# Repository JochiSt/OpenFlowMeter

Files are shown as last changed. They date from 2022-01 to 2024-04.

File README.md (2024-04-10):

# OpenFlowMeter
## Purpose
Measuring flow of gases and maybe liquids. 

## Principle
Measures the volume flow by the amount of heat transferred to a gas flow. This can be either done by constantly heating the sensor or by evaluating temperature cycles.

# Hardware
The hardware is based around two voltage controlled current sources, which are controlled and readout via a STM32F103 microcontroller. 
The controller provides the ADCs for reading the voltages and current as well as the digital communication to the outside of the PCB.

## Photographs of the populated PCB
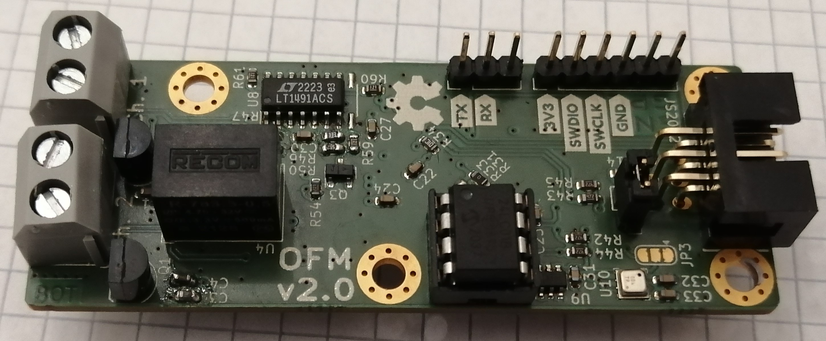
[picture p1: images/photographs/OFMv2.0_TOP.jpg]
Picture of the PCB from TOP side


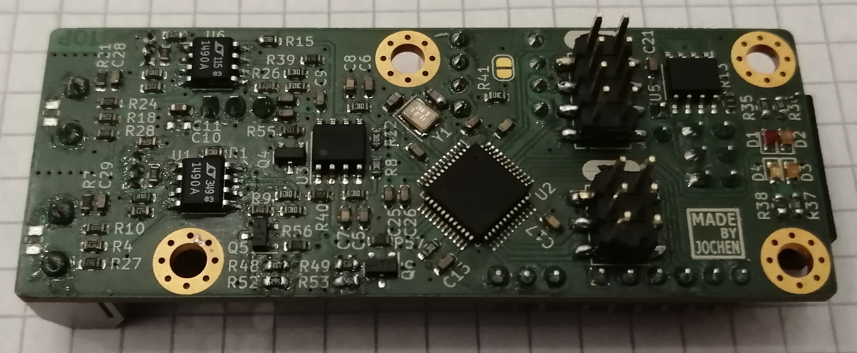
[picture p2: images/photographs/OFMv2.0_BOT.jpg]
Picture of the PCB from BOT side


# References
The working principle of this device is adapted from a proposal of the LHC gas group at CERN. In addition there is a report of a student, explaining / proposing this technique more in detail.

[1] [M. van der Klis. PT100 channel flow meter for the LHC experiments, Technical Student Report Feb. 2001](https://cernbox.cern.ch/s/Kf3zl0SAsNUGON4)

[2] [F.Hahn, S.Haider, M. v.d. Klis, C. Zinoni, Proposal for a gas flow meter at LHC, 10.2.2001](https://cernbox.cern.ch/s/3Rpv9e0gEgKwOim)

# PCBs
PCBs are available from AISLER https://aisler.net/p/MVHMBVKT

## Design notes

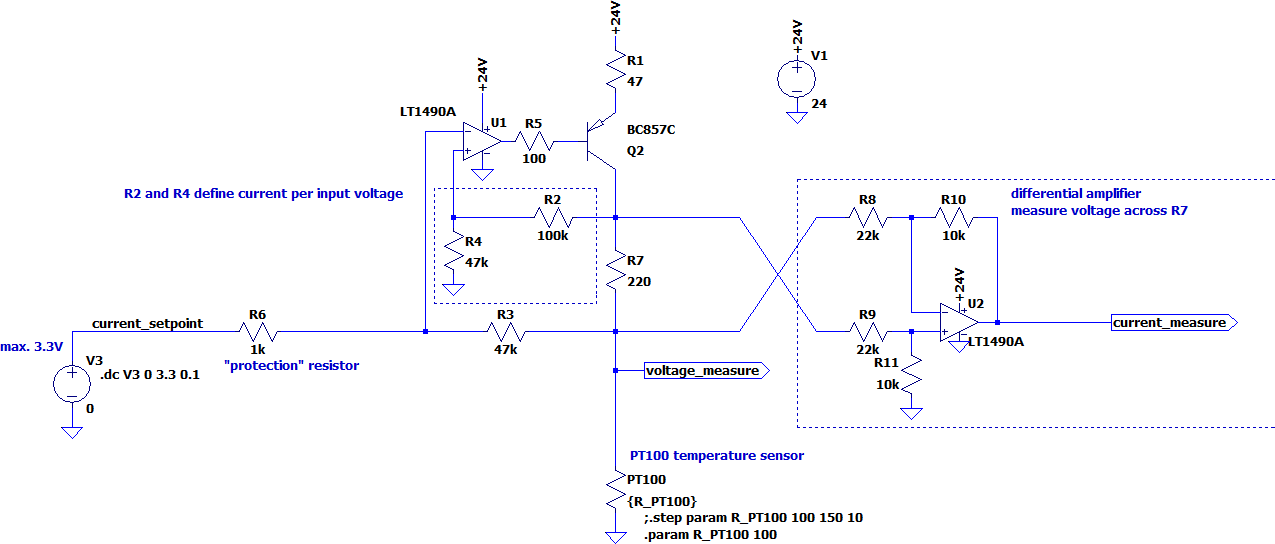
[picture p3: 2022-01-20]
simulations/CurrentSource/images/current_source_mod_v1_schematic.PNG

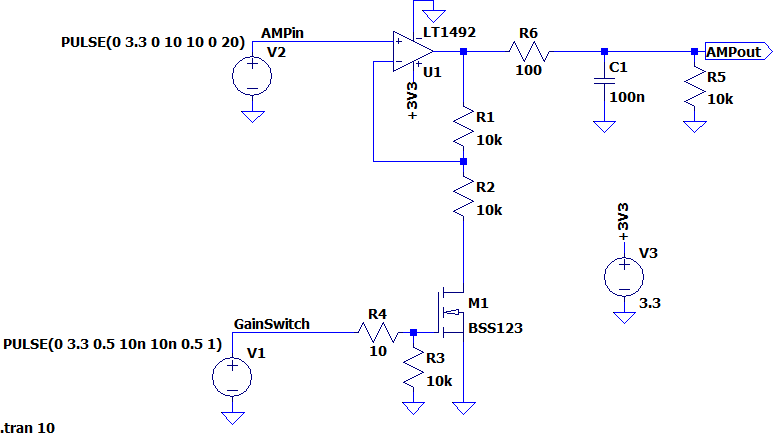
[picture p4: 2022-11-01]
simulations/GainSwitchAmplifier/images/GainSwitchAmplifier_Schematic.png

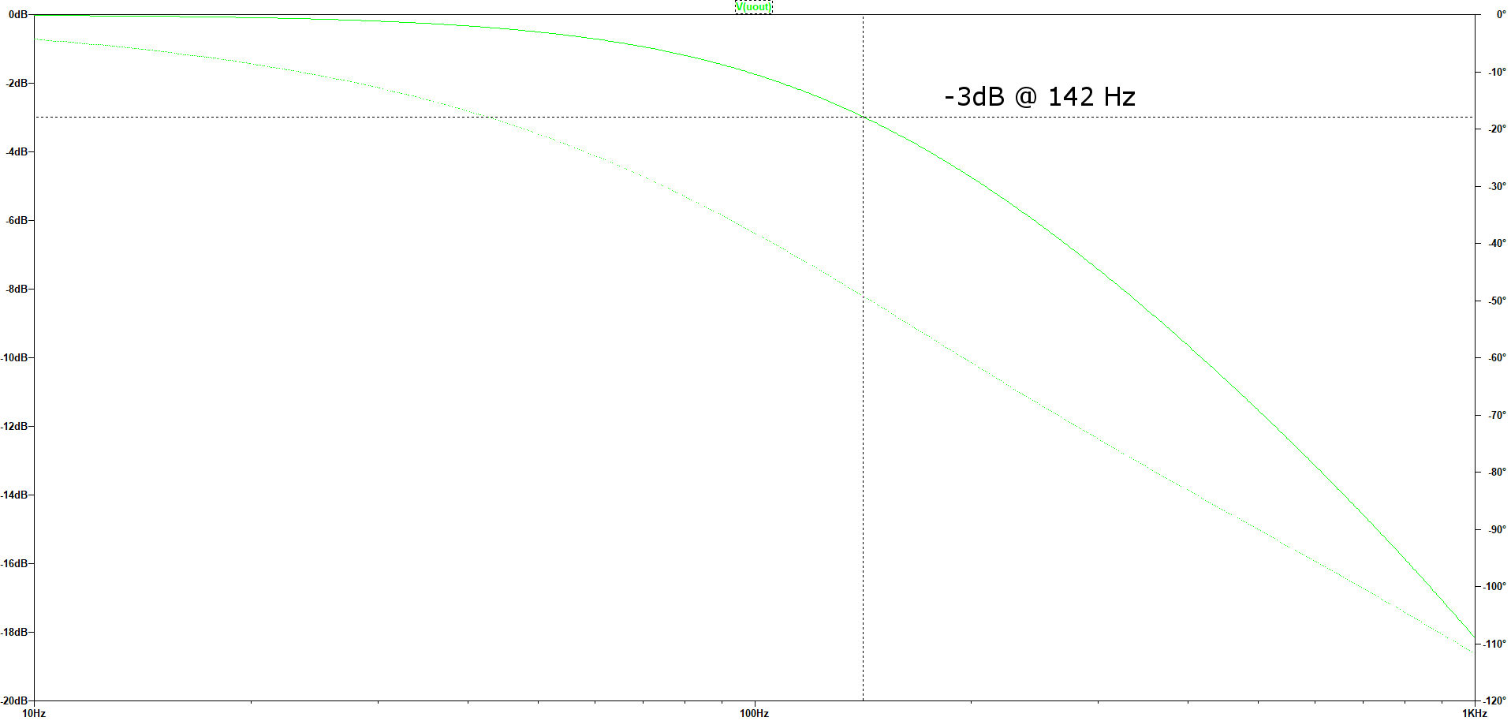
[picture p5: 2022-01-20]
simulations/PWMFilter/images/ACtransfer.png

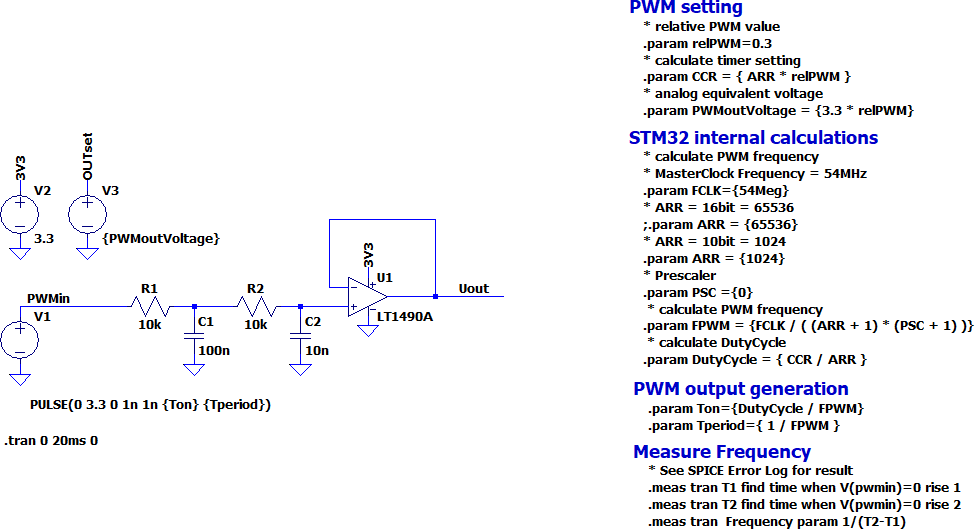
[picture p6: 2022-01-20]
simulations/PWMFilter/images/PWMfilter_sch.PNG

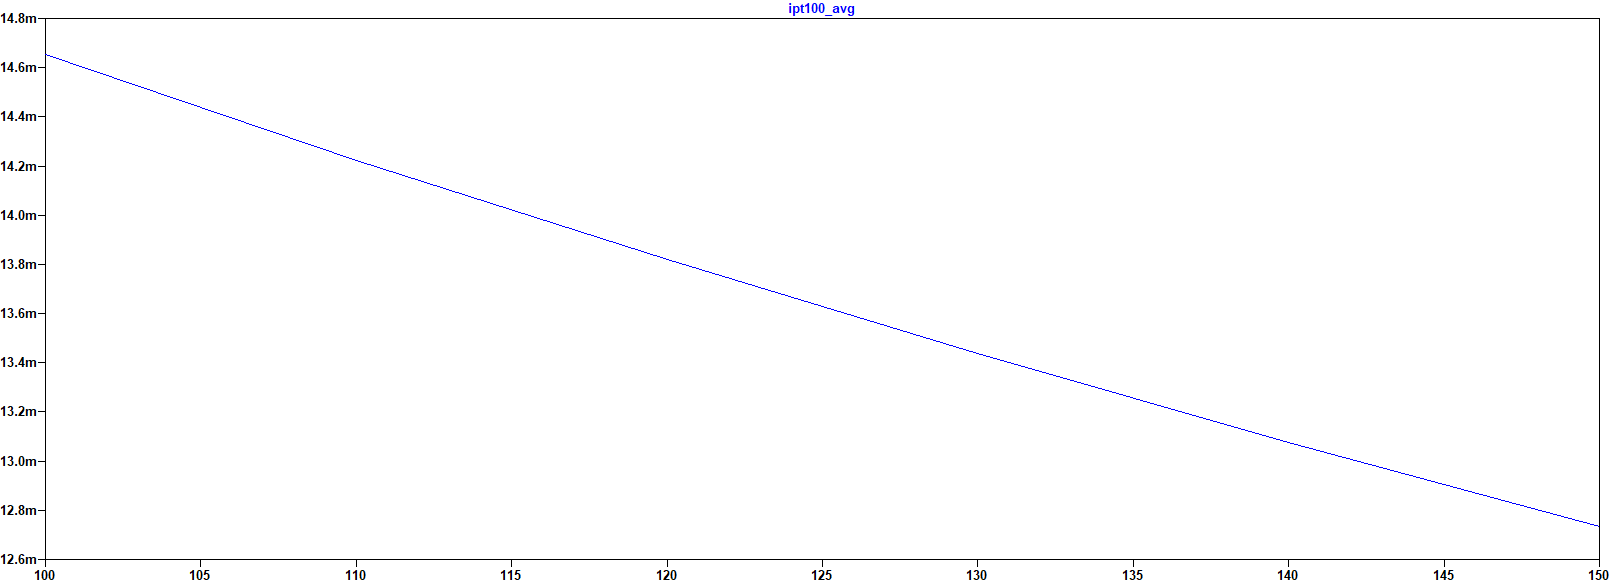
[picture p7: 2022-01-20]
simulations/CurrentSource/images/current_source_mod_v1_current_vs_PT100.png

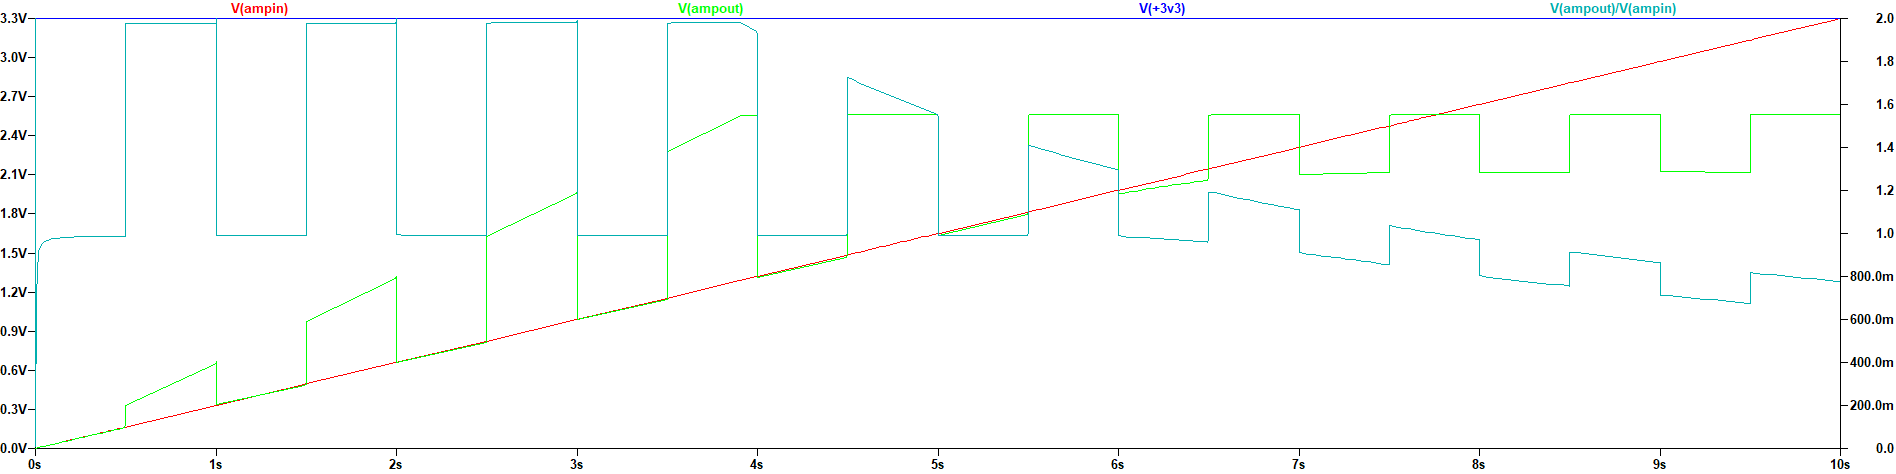
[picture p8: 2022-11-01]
simulations/GainSwitchAmplifier/images/GainSwitchAmplifier_Waveform.png

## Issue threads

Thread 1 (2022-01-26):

I2C pullup resistors

JochiSt, 2022-01-26:
In PCB revision 1 the pullup resistors for the I2C are missing.

There should be 4k7 pullups for both I2C busses (each SDA and SCL).

JochiSt, 2022-01-26:
implemented I2C pullups in 2a67918aacebdc1d0675151e68e6d52e4de8d5ff

pushed project to AISLER as well. Wait for commissioning of the first board before really going into a new interation.

Closed 2022-01-26.

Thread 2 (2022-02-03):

commissioning of 1st board

JochiSt, 2022-02-03:
## Logbook of the commissioning of the first board

JochiSt, 2022-02-03:
## USART

The USART is working at 115200.

JochiSt, 2022-02-06:
## CAN Bus

CAN Bus working, both RX and TX.

Note:
for RX the CAN filter must be set. There are two FIFOs, which can be handled via an interrupt.

JochiSt, 2022-02-06:
## ADC
Getting the timer into operation.
Channel 4: Output Compare No Output
Mode: Toggle on Output

ADC is triggered on Timer 4 Capture Compare 4

Quite helpful:
* https://www.bartslinger.com/stm32/stm32-cubemx-timer-adc-dma-configuration/

JochiSt, 2022-02-06:
## PWM

Works 512 = 1.65V 1024 = 3.3V

JochiSt, 2022-11-03:
First board was quite successful, some issues found, which are going to be fixed in revision 2.0. See #11 for commissioning of the new revision.

Closed 2022-11-03.

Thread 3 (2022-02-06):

Get rid of TIM4 for ADC trigger

JochiSt, 2022-02-06:
TIM4 is the trigger for the ADC conversion. There is no need for this.

This can also been done by TIM2 or on the other hand manually in the main loop, which is also triggered by TIM2.

JochiSt, 2022-02-07:
Previous configuration is described in https://github.com/JochiSt/OpenFlowMeter/issues/2#issuecomment-1030868442

Closed 2022-02-07.

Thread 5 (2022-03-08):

Non linearity of current and voltage

JochiSt, 2022-03-08:
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

When looking at the calibration, there is a non linearity observable, which effects both current and voltage.

JochiSt, 2022-03-08:
The current measured by the Multimeter and the DAC setting have a quite linear dependence.
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

JochiSt, 2022-03-08:
This behaviour might be caused by the 3V5 Zener diodes, which limit the voltage to the ADC inputs.

JochiSt, 2022-03-08:
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

By using a simulation, it is possible to reconstruct this issue.

JochiSt, 2022-03-08:
By removing the Zener Diode and replacing R27,R28,R39,R40 with 56k, the result looks quite linear.
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

JochiSt, 2022-03-09:
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

Also with more points, the behaviour stays linear.

But, on the other hand, if no load or a very high ohmic load is connected, this might damage the controller.

Closed 2022-03-08.

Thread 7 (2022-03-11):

Calibration using 100Ohm

JochiSt, 2022-03-11:
I tested the OFM using two 100 Ohm resistors and a DAC sweep. (From the calibration, it is known, that 32 LSB DAC are about 1mA measurement current)

### Channel 0
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

### Channel 1
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

Overall it seems, that there is a bit to much noise for the low voltages (and currents). This needs further investigations, whether there is some room for improvements.

JochiSt, 2022-03-11:
Added 100nF at the position of D5 and D6.

JochiSt, 2022-03-11:
Since this effects only channel 0, the results DAC sweep looks more smooth.

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

And the precision has also increased. Maybe further capacitors are needed to stabilise the measurement circuit.

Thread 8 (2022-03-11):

Heat dissipation in the PNP transistors

JochiSt, 2022-03-11:
When having a look at the thermal image (sorry for the bad quality) one can observe two hot spots, which are the PNP transistors of the current source. For the first prototype they are SOT23 - quite small and running at a DAC of 768 for a longer time causes them to raise their temperature.
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

For the next prototype a through hole transistor or a larger package including some cooling area might be a good choice.

JochiSt, 2022-03-12:
Replacing the BC856 with a BC558 might be a good choice, the BC558 can withstand 100mA continuos collector current. This should reduce the device temperature further.

JochiSt, 2022-11-01:
Replaced the BC856 with BC556 in #10

Closed 2022-11-01.

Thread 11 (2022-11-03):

commissioning of revision 2.0

JochiSt, 2022-11-03:
This issue is about the commissioning of the first board of rev 2.0.

The firmware is prepared and should hopefully work out of the box.

JochiSt, 2022-12-13:
# Population changes
* `C19` & `C20` 22p instead of 27p
* SGM8522XS instead of LT1492 (LT1490A)
* TMP101 instead of TMP100

JochiSt, 2022-12-13:
Startup working:

## I2C Bus Scanning
```
I2C bus #1
Scanning I2C bus:
.......................................................................0x48.............................................0x76.........
```
Two devices as expected found:
* 0x48 = TMP101
* 0x76 = BME688

JochiSt, 2022-12-13:
When the EEPROM (24LC01) is inserted it is also recognised on I2C Bus 1
```
0x48.......0x50 0x51 0x52 0x53 0x54 0x55 0x56 0x57..............................0x76.........
```

JochiSt, 2022-12-16:
### Gain of I and U
#### Channel 0
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

#### Channel 1
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

Should be dominated by the low gain for low DAC settings and by the saturation for the high DAC settings.

JochiSt, 2022-12-16:
Gain vs DAC settings. A bit better plot than before.
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

The resistance calculated from the data above.
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

Because the current / voltage resolution could be better, I'll decrease `R50`, `R51`, `R52`, `R53` to increase the gain.

JochiSt, 2022-12-20:
reading and writing the configuration works.

### example setting TMP100 interval to 64
```
Getting the configuration from OFM
Board ID: 1
Intervals:
	CAN ADC    4
	Print UART 8
		I2C TMP100 1
		I2C BME680 255

PIDflags 0x0
PID 0
	T: 40.000000
	P: 0.000000
	I: 0.000000
	D: 0.000000

PID 1
	T: 40.000000
	P: 0.000000
	I: 0.000000
	D: 0.000000

Smoothing:
	SMOO     15
	SMOO_MAX 16
```
Here is the change done, the interval is set to 64. (**Note:** sometimes, this does not work on the first try. But this might be related to the CAN bus...)
```
Board ID: 1
Intervals:
	CAN ADC    4
	Print UART 8
		I2C TMP100 64
		I2C BME680 255

PIDflags 0x0
PID 0
	T: 40.000000
	P: 0.000000
	I: 0.000000
	D: 0.000000

PID 1
	T: 40.000000
	P: 0.000000
	I: 0.000000
	D: 0.000000

Smoothing:
	SMOO     15
	SMOO_MAX 16
```

JochiSt, 2022-12-20:
After triggering the writing of the configuration into the EEPROM, the configuration is changed on reboot / power cycling.

JochiSt, 2022-12-22:
## internal PID working
**Note:** not tuned to any performance, but with a simple `P` of `0.9` this algorithm starts regulating the temperature.

The PID was enabled just for channel 1 (the lower plot in the image)
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

JochiSt, 2022-12-22:
With this all major components of the board are working. (Except BME680, which I have not yet implemented).

Closed 2022-12-22.

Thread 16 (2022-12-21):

Channel numbering

JochiSt, 2022-12-21:
At some places, there might be still a mix up between `Channel 1` (`Ch0` in software) and `Channel 2` (`Ch1` in software).

This should be fixed at some point.

What to check:
- [x]  DAC setpoint
- [x]  PID controller assignment
- [x]  ADC readout

JochiSt, 2023-01-04:
As far as I can judge this by now, at least the calibration works fine, if the silkscreen 'Ch. 2' just gets replaced by 'Ch. 0'.

JochiSt, 2023-01-05:
The channel numbering on the PCB side should be fixed by 378b34f6856afaaad9e5074813aaa0a885865eb9

Closed 2023-01-05.

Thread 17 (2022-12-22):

PID algorithm tuning

JochiSt, 2022-12-22:
## first tests

The first tests of the PID are quite promising.

Here the change of the setpoint while the sensor is isolated. (Channel 0 is connected to an 100 Ohm resistor)
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

JochiSt, 2023-02-27:
PID is also working fine with the 4096 LSB DAC

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

Note: PT100 only on CH1

Closed 2023-03-06.

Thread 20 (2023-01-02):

Implementation of the optimised gain settings

JochiSt, 2023-01-02:
In #18 a optimised gain setting has been found, which needs to be implemented in hardware (exchange of resistors) and software (configuration values).

The results from #18 are:
**U channel:**
*    R1 = 330k
*    R2 = 56k

**I channel:**
*    R1 = 470k
*    R2 = 56k

JochiSt, 2023-01-02:
### TODOs:

PCB changes:
- [ ] current source 1
    - [ ]  R1 / R2 U
    - [ ]  R1 / R2 I
- [ ] current source 2
    - [ ]  R1 / R2 U
    - [ ]  R1 / R2 I

- [ ] write configuration into EEPROM
- [ ] test variable gain setting

JochiSt, 2023-01-03:
There is a problem with reading back the gain settings see #21.

JochiSt, 2023-01-03:
I've implemented sending out the measured and calculated temperatures.

These are the values, the PID is working on.
It seems, that this needs a bit of tuning to get the best results. Especially in the region, where two different gain settings are used, the behavior can be better.

JochiSt, 2023-01-03:
I've implemented sending out the measured and calculated temperatures.

These are the values, the PID is working on.
It seems, that this needs a bit of tuning to get the best results. Especially in the region, where two different gain settings are used, the behavior can be better.

A current calibration in order to determine the real gain of the amplifier seems a good next step.

JochiSt, 2023-01-04:
The pink curve is the internal used temperature, the wiggles at about 100s might be a problem for the PID controller.

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

JochiSt, 2023-01-05:
The gain setting resistors listed in https://github.com/JochiSt/OpenFlowMeter/issues/20#issue-1516488905 are by a factor of 10 to large.

Those values cause might cause the amplifier to cause strange effects in the unity gain setting. (see https://github.com/JochiSt/OpenFlowMeter/issues/22#issue-1518569229)

This problematic was solved in https://github.com/JochiSt/OpenFlowMeter/issues/22#issuecomment-1371897907.

The correct gain setting resistors are (Ch0):
* R47 = 47k
* R51 = 5k6
* R46 = 33k
* R50 = 5k6

And same for Ch 1.

JochiSt, 2023-01-09:
From the `HG` to the `LG` of the current section, there is some slight mismatch, which causes the temperature to be negative. (Means, that a too high current is measured)

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

JochiSt, 2023-01-10:
The gain switching is working. Although it needs some improvements. (There is always room to improve things)

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

Closed 2023-01-10.

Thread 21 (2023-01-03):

Problem getting I gains from configuration

JochiSt, 2023-01-03:
There is a problem getting the gains via CANbus from the OFM

The log of the address and content:
```
Getting the configuration from OFM
0 1
1 4
2 8
3 16
4 255
5 15
6 16
7 0
8 0
9 0
10 32
11 66
12 0
13 0
14 0
15 0
16 0
17 0
18 0
19 0
20 0
21 0
22 0
23 0
24 0
25 0
26 32
27 66
28 0
29 0
30 0
31 0
32 0
33 0
34 0
35 0
36 0
37 0
38 0
39 0
40 73
41 146
42 220
43 64
44 37
45 73
46 22
47 65
48 73
49 146
50 220
51 64
52 37
53 73
54 22
55 65
```

Which then gets converted into:
```
Board ID: 1
Intervals:
	CAN ADC    4
	Print UART 8
		I2C TMP100 16
		I2C BME680 255

PIDflags 0x0
PID 0	deactivated
	T: 40.000000
	P: 0.000000
	I: 0.000000
	D: 0.000000

PID 1	deactivated
	T: 40.000000
	P: 0.000000
	I: 0.000000
	D: 0.000000

Smoothing:
	SMOO     15
	SMOO_MAX 16

Amplification:
	U0: 6.892857
	I0: 8.000000
	U1: 6.892857
	I1: 0.000000
```
The gain for `U0` and `U1` are fine but the gains for the currents are somehow strange. They do not match the default configuration, which is stored inside the OFM.

Especially the gain for `I1` is zero in the parsed configuration but nonzero in the raw packets. (Should be the last 4 bytes).

JochiSt, 2023-01-03:
This issue could be fixed using commit 5c1b0ffcbd467b752efde9fe7353595dff08f398.

Closed 2023-01-03.

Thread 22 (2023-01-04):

Current Calibration v2

JochiSt, 2023-01-04:
## Channel 0
### High Gain

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

The current fits the measured current with the multimeter quite well (99.5%). There seems to be an issue with the low gain channel in the low current regime. (see the gray / black oscillations)

The residuals also look promising:

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

JochiSt, 2023-01-04:
## DAC steps

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

The dac step fit for version 2 is the same than the one for version 1. There is 1 LSB difference.

JochiSt, 2023-01-04:
## Channel 1

### High gain

In this channel the wiggles of the low gain are not observable. I suspect an issue with the gain switching amplifier here.

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

JochiSt, 2023-01-05:
To exclude the problems with the gain switching amplifier, I reduced the resistors by a factor of 10, so that R47 = 47k and R51 = 5k6. Same for R46 = 33k and R50 = 5k6.

JochiSt, 2023-01-05:
By using the lower resistors, this effect is gone. There is now a gain mismatch, but this might be wrong population of the resistors. If I get this channel working, I'll update the other one as well.

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

JochiSt, 2023-01-05:
The gain mismatch was a swap of the population, I did not mirror the board. Thus the U gain and I gain has been mixed up.

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

JochiSt, 2023-01-05:
### CH0 voltage and current bias
It seems, that there is a slight voltage and current bias in the low gain with respect to the high gain. (see attached image)

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

This can be calibrated out (not working 100% in the image above) and by this the measured resistances match much better.

JochiSt, 2023-01-06:
The offsets have been implemented in b254d9760f564fae4d8d9865fb7bdbdeee8afc4e. The default values are somewhat arbitrary, they have to be tuned to match the exact board.

JochiSt, 2023-01-06:
## Offsets
after tuning the offsets, the resistance at the saturation border of the high gain is rather smooth between HG and LG.

### CH0

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

### CH1

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

JochiSt, 2023-01-08:
The PID starts working better and better. Also the gain switching is working.

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

The usage of different gains for voltage and current needs some further investigations.

JochiSt, 2023-03-06:
Since v3 will have a offset voltage included to get a higher resolution at higher currents, I close this issue here and in case it is needed, I'll open a new one.

Closed 2023-03-06.

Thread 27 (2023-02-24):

Switchable Gain with Offset

JochiSt, 2023-02-24:
When the sensor is heated, the current is e.g. 20mA, by this the voltage created by this is 2V. This means, that the resistance changes are biased with this

Similar to the gain switching amplifier #9 a bias, which is subtracted would be ideal.

This can be achieved with a similar structure.

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

The voltage can be generated by e.g. two additional timer channels.

JochiSt, 2023-02-26:
The resistive divider of R7 and R8 is not strictly needed.

JochiSt, 2023-02-27:
Using a analog switch yields a better result (see b1855a238db8a5da4ba2636cf99099591b647a84)

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

JochiSt, 2023-03-05:
Using a CD4066, the amplifier can now be biased. There is one bias for CH0 and one for CH1.
I've the hope, that the I and U bias match. Otherwise, some resistors might be needed here.

Closed 2023-03-05.

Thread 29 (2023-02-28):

Cable length influence (2/3/4 wire connection)

JochiSt, 2023-02-28:
For the implemented two wire connection, the wire resistance spoils the temperature with its bias resistance.

A three wire / four wire connection might be better than the existing two wire connection. But this needs proper evaluation first.

JochiSt, 2023-03-02:
Four wire connection is rather difficult to implement, because this would require an additional differential amplifier stage at the PT100 input.

JochiSt, 2023-03-05:
The 4 wire connection is implemented by using a differential amplifier. This should cancel out the cable losses.

Closed 2023-03-05.

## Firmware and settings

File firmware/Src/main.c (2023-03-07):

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
/* Includes ------------------------------------------------------------------*/
#include "main.h"
#include "adc.h"
#include "can.h"
#include "dma.h"
#include "i2c.h"
#include "spi.h"
#include "tim.h"
#include "usart.h"
#include "gpio.h"

/* USER CODE BEGIN Includes */
#include "syscalls.h"
#include "utils.h"
#include "i2c_scanner.h"
#include "i2c_utils.h"
#include "config.h"
#include "eeprom_cfg.h"

#include "pid.h"

#include <stdbool.h>
/* USER CODE END Includes */

/* USER CODE BEGIN PD */
/******************************************************************************/
/**
 * select, what should be printed via UART
 */
//#define PRINT_UART_PID          // print PID performance
//#define PRINT_UART_ADC        // print the ADC data
//#define PRINT_UART_CALC_TEMP  // print the calculated temperatures
/******************************************************************************/
/**
 * PCB v1 compatibility mode
 */
#define PCB_V1
/******************************************************************************/
/**
 * PCB v2 compatibility mode
 * enables:
 *  - dual gain ADC readout
 *  - I2C sensor readout
 */
//#define PCB_V2
#if defined(PCB_V2)
#undef PCB_V1
#define I2C_SENSOR_READOUT
#endif
/******************************************************************************/
/**
 * PCB v3 compatibility mode
 * enables:
 *  - dual gain ADC readout
 *  - offset for ADC / differential amplifier
 *  - I2C sensor readout
 */
//#define PCB_V3
#if defined(PCB_V3)
#undef PCB_V1
#undef PCB_V2
#define I2C_SENSOR_READOUT
#endif
/******************************************************************************/
/**
 * Write the configuration at startup into the EEPROM
 */
//#define WRITE_DEFAULT_CFG_EEPROM_STARTUP

/* USER CODE END PD */


/* USER CODE BEGIN PV */
/// pointer to the current setting PWM
volatile uint32_t *PWMcurrent[2] = {&TIM3->CCR2, &TIM3->CCR1};
/// current
float current[2];
/// voltage
float voltage[2];
/// temperature
float temperature[2];

#if defined(PCB_V3)
  // There are two offsets one for each channel
  float offset[2];
  volatile uint32_t *PWMoffset[2] = {&TIM2->CCR2, &TIM2->CCR1};
#endif

// avoid flickering saturation non saturation
#define SAT_CNT_PRESET  10
uint8_t current_sat_cnt[2];
uint8_t voltage_sat_cnt[2];

/// output from PID, which is connected to the PWM output, if the PID is active
uint16_t PIDout[2];


/* USER CODE END PV */

void SystemClock_Config(void);
/**
  * @brief  The application entry point.
  * @retval int
  */
int main(void)
{
  /* MCU Configuration--------------------------------------------------------*/

  /* Reset of all peripherals, Initializes the Flash interface and the Systick. */
  HAL_Init();

  /* Configure the system clock */
  SystemClock_Config();

  /* Initialize all configured peripherals */
  MX_GPIO_Init();
  MX_DMA_Init();
  MX_ADC1_Init();
  MX_CAN_Init();

  MX_I2C1_Init();
  MX_I2C2_Init();

  MX_USART1_UART_Init();

  MX_SPI2_Init();

  MX_TIM1_Init();
  MX_TIM2_Init();
  MX_TIM3_Init();
  MX_TIM4_Init();

  /* USER CODE BEGIN 2 */
  /****************************************************************************/
  printf("\r\n\r\n");
  printf("Compiled at "__DATE__" - "__TIME__"\r\n");
  printf("Compiled with GCC Version "__VERSION__"\r\n");

#if defined(PCB_V1)
  printf("PCB version 1\r\n");
#elif defined(PCB_V2)
  printf("PCB version 2\r\n");
#elif defined(PCB_V3)
  printf("PCB version 3\r\n");
#endif
  /****************************************************************************/
  // all OFF
  LED_ERROR(SET);    // red      -> failure
  LED_CANRX(SET);    // yellow   -> RX
  LED_CANTX(SET);    // yellow   -> TX
  LED_STATUS(SET);   // green    -> TIM2

  // all LEDs ON
  LED_ERROR(RESET);
  HAL_Delay(500);
  LED_CANRX(RESET);
  HAL_Delay(500);
  LED_CANTX(RESET);
  HAL_Delay(500);
  LED_STATUS(RESET);

  HAL_Delay(1000);

  // do an I2C scan of both I2C ports
  i2c_scan(&hi2c1);   // PORT 1
  i2c_scan(&hi2c2);   // PORT 2

  // all LEDs off
  LED_ERROR(SET);
  HAL_Delay(500);
  LED_CANRX(SET);
  HAL_Delay(500);
  LED_CANTX(SET);
  HAL_Delay(500);
  LED_STATUS(SET);
  /****************************************************************************/
  // read all configuration values from I2C EEPROM, or use default ones
  generateDefaultCFG(&cfg);
  generateDefaultCFG(&default_cfg);

  printf("\r\n\r\nDEFAULT config:\r\n");
  printCfg(&default_cfg);

#if defined(WRITE_DEFAULT_CFG_EEPROM_STARTUP)
  write_EEPROM_cfg(&hi2c1, &default_cfg);
#endif

  read_EEPROM_cfg(&hi2c1, &cfg, &default_cfg);

  printf("\r\n\r\nEEPROM config:\r\n");
  printCfg(&cfg);

  // link configuration to PID controllers
  for(int i=0; i<2; i++){
    pid[i].PIDcfg = &cfg.PID[i];
    pid[i].input  = &temperature[i];
    pid[i].output = &PIDout[i];
  }

  printf("\r\n\r\n");
  /****************************************************************************/
  // START CAN Bus (required for transmission of messages)
  printf("starting CAN Bus...\r\n");
  HAL_CAN_Start(&hcan);

  // prepare CAN filter for receiving messages
  // FIFO 0
  CAN_prepare_filter_id(
      CAN_CONFIG_ID | (cfg.board_ID << 4),
      CAN_DAC_ID    | (cfg.board_ID << 4),
      0);
  // FIFO 1
  //CAN_prepare_filter_id(0x125, 0x126, 1);   // not needed?

  // activate notifications
  if(HAL_CAN_ActivateNotification(&hcan, CAN_IT_RX_FIFO0_MSG_PENDING)!= HAL_OK){
	  Error_Handler();
  }
  if(HAL_CAN_ActivateNotification(&hcan, CAN_IT_RX_FIFO1_MSG_PENDING)!= HAL_OK){
	  Error_Handler();
  }
  /****************************************************************************/
  printf("starting periodic timer TIM1...\r\n");
  HAL_TIM_Base_Start_IT(&htim1);

#if defined(PCB_V3)
  // PWM for driving the bias of the amplifier
  printf("starting TIM2 PWM...\r\n");
  HAL_TIM_PWM_Start(&htim2, TIM_CHANNEL_1); // start channel 1
  HAL_TIM_PWM_Start(&htim2, TIM_CHANNEL_2); // start channel 2

  // Initialize PWM outputs with 0
  TIM2->CCR1 = 0; // set channel 1
  TIM2->CCR2 = 0; // set channel 2
#endif

  // PWM for driving the current sources
  printf("starting TIM3 PWM...\r\n");
  HAL_TIM_PWM_Start(&htim3, TIM_CHANNEL_1); // start channel 1
  HAL_TIM_PWM_Start(&htim3, TIM_CHANNEL_2); // start channel 2

  // Initialize PWM outputs with 0
  TIM3->CCR1 = 0; // set channel 1
  TIM3->CCR2 = 0; // set channel 2

  /****************************************************************************/
  // Calibrate The ADC On Power-Up For Better Accuracy
  printf("calibrating ADC...\r\n");
  HAL_ADCEx_Calibration_Start(&hadc1);

  /****************************************************************************/
#if defined(I2C_SENSOR_READOUT)
  // Test of TMP100 / TMP101
  i2c_init_TMP100(&hi2c1, 0x48);
  i2c_read_TMP100(&hi2c1, 0x48);
#endif

  // start ADC DMA
  printf("starting ADC DMA...\r\n");
  // start first ADC conversion
  HAL_ADC_Start_DMA(&hadc1, adcBuf, ADC_BUFLEN); //Link DMA to ADC1
  /****************************************************************************/
  // create a pointer map for easy access
  // low gain
  avr_current[0][0] = &avr_adcBuf_GAIN_0[0];
  avr_voltage[0][0] = &avr_adcBuf_GAIN_0[1];
  avr_current[1][0] = &avr_adcBuf_GAIN_0[2];
  avr_voltage[1][0] = &avr_adcBuf_GAIN_0[3];

  // high gain
  avr_current[0][1] = &avr_adcBuf_GAIN_1[0];
  avr_voltage[0][1] = &avr_adcBuf_GAIN_1[1];
  avr_current[1][1] = &avr_adcBuf_GAIN_1[2];
  avr_voltage[1][1] = &avr_adcBuf_GAIN_1[3];
  /* USER CODE END 2 */

  /* Infinite loop */
  /* USER CODE BEGIN WHILE */

  /// store the old timer2 value
  uint8_t timer_elapsed_old = 0;

  // variables for transmitting CAN messages
  uint8_t cnt_can_adc = 0;        ///< counter for the CAN ADC message rate

#if defined(I2C_SENSOR_READOUT)
  uint8_t cnt_can_i2c_tmp100 = 0; ///< counter for the CAN I2C TMP100 rate
  uint8_t cnt_can_i2c_bme680 = 0; ///< counter for the CAN I2C BME680 rate
#endif

  uint8_t cnt_print_uart = 0;     ///< counter for UART output

  uint8_t ADCgainUsed = 0;        ///< which ADC gain is used for calculation

  /****************************************************************************/
  printf("successfully started everything\r\n");
  // Main loop
  while (1)
  {
    /* USER CODE END WHILE */

    /* USER CODE BEGIN 3 */
    /**************************************************************************/
    // CAN message handling is done in CAN_parse_message in can.c
    if (can_message_received){
      CAN_parse_message(RxHeader, RxData);
      can_message_received = 0;
    }

    /***************************************************************************
     * check whether a new ADC result has been taken, wait a short time for
     * everything to settle and trigger a new conversion
     **************************************************************************/
    if (adc_result_received){
      adc_result_received = 0;
      HAL_Delay(2);
      HAL_ADC_Start_DMA(&hadc1, adcBuf, ADC_BUFLEN);
    }

    /***************************************************************************
     * check timer 2 for doing periodic tasks
     * one timer2_elapsed is equal to 125ms
     **************************************************************************/
    if( timer_elapsed >= timer_elapsed_old){
        timer_elapsed_old = timer_elapsed + 1;	// important to add +1, in
                                                  // order to catch overflow

        // increase the interval counters every time this counter is evaluated
        cnt_can_adc++;
        cnt_print_uart++;

#if defined(I2C_SENSOR_READOUT)
        cnt_can_i2c_tmp100++;
        cnt_can_i2c_bme680++;
#endif

        /***********************************************************************
         * PID handling
         * for the PID, it is important, that it is triggered with a constant
         * frequency.
         */
        // calculate current and voltage of each channel
        // use the highest possible gain

        ADCgainUsed = 0;

        // calculate coarse current and voltage for each channel
        for(int i=0; i<2; i++){
          current[i] = (*avr_current[i][0] * LSB2I) + cfg.GAIN[i].Ibias/1000.;
          voltage[i] = (*avr_voltage[i][0] * LSB2U) + cfg.GAIN[i].Ubias;
        }

#if defined(PCB_V2)
        for(int i=0; i<2; i++){

          if( *avr_current[i][1] < ISATURATION_LSB ){
            // high gain setting
            if(!current_sat_cnt[i]){
              current[i] = *avr_current[i][1] * LSB2I / cfg.GAIN[i].Igain;
              ADCgainUsed |= (1 << (0 + 2*i));
            }else{
              current_sat_cnt[i]--;
            }
          }else{
            current_sat_cnt[i] = SAT_CNT_PRESET;
          }

          if( *avr_voltage[i][1] < USATURATION_LSB ){
            // high gain setting
            if(!voltage_sat_cnt[i]){
              voltage[i] = *avr_voltage[i][1] * LSB2U / cfg.GAIN[i].Ugain;
              ADCgainUsed |= (1 << (1 + 2*i));
            }else{
              voltage_sat_cnt[i]--;
            }
          }else{
            voltage_sat_cnt[i] = SAT_CNT_PRESET;
          }
        }
#elif defined(PCB_V3)
        // get the offset voltage
        for(int i=0; i<2; i++){
          offset[i] = 3.3 * (*PWMoffset[i]) / 4096;
        }

        // adjust the offset voltage

        // if offset voltage is fine, we can use the high gain

#endif
        /** calculate temperatures ********************************************/
        for(int i=0; i<2; i++){
          temperature[i] = convertPT100_R2T( voltage[i] / current[i] );
        }

        /** run the PID controllers *******************************************/
        for(int i=0; i<2; i++){
          runPID(&pid[i]);

          /** update the output, if the PID is active *************************/
          if(pid[0].active){
            *PWMcurrent[i] = PIDout[i];
          }else{
            *PWMcurrent[i] = PWM[i];
          }
        }

        // link the PID active to the configuration active
        pid[0].active = cfg.PID_flags.PID0_active;
        pid[1].active = cfg.PID_flags.PID1_active;
    }

    /*************************************************************************
     * Print some variables via UART
     ************************************************************************/
    if( cnt_print_uart >= cfg.interval_PRINT_UART
        && cfg.interval_PRINT_UART < 255
        ){
      cnt_print_uart = 0;

#if defined(PRINT_UART_ADC)
      printf("collected ADC results %d\r\n", adc_result_cnt);
      // reset ADC result counter
      adc_result_cnt = 0;

      // printout collected data
      // first 4 samples are from current sources
      for(uint8_t i = 0; i<4; i++){
        printf("%d\t", avr_adcBuf_GAIN_0[i]);
      }
      printf("\r\n");
      for(uint8_t i = 0; i<4; i++){
        printf("%d\t", avr_adcBuf_GAIN_1[i]);
      }
      printf("\r\n");

      printf("T= %ld\tU= %ld\r\n", adcBuf[4], adcBuf[5]);

#endif
#if defined(PRINT_UART_PID)
      for(int i=0; i<2; i++){
        printf("PID%d %d\r\n",  i, pid[0].active);
        printf(" - I   %f\r\n",  current[i]);
        printf(" - U   %f\r\n",  voltage[i]);
        if(i==0){
          printf(" - PWM %ld\r\n", TIM3->CCR2);
        }else{
          printf(" - PWM %ld\r\n", TIM3->CCR1);
        }
        printf(" - Tm  %f\r\n",  temperature[i]);
        printf(" - Ts  %f\r\n",  pid[i].PIDcfg->PID_T );
        printf(" - P   %f\r\n",  pid[i].PIDcfg->PID_P );
        printf(" - I   %f\r\n",  pid[i].PIDcfg->PID_I );
        printf(" - D   %f\r\n",  pid[i].PIDcfg->PID_D );
      }
#endif
#if defined(PRINT_UART_CALC_TEMP)
      printf("Temperatures:\r\n");
      printf("ADC gain selection %x \r\n", ADCgainUsed);
      for(int i=0; i<2; i++){
        printf("CH%d: %f\r\n", i, temperature[i]);
        printf(" - I   %f\r\n",  current[i]);
        printf(" - U   %f\r\n",  voltage[i]);
      }
#endif
    }

    /***************************************************************************
     * Send out periodic CAN messages for ADC
     **************************************************************************/
    // ADC CAN message
    if( cnt_can_adc >= cfg.interval_CAN_ADC && cfg.interval_CAN_ADC < 255) {
        // reset CAN timer counter
        cnt_can_adc = 0;

        // TODO remove debug CAN message transmission
        //CAN_send_DAC_readback();
        CAN_send_uint16s(CAN_DAC_ID         | (cfg.board_ID << 4),
                             3, *PWMcurrent[0], *PWMcurrent[1], (uint16_t)ADCgainUsed );
        CAN_send_floats( CAN_TEMPERATURE_ID | (cfg.board_ID << 4) ,
                                                  &temperature[0], &temperature[1]);
        CAN_send_floats( CAN_VOLTAGE_ID     | (cfg.board_ID << 4) ,
                                                  &voltage[0], &voltage[1]);
        CAN_send_floats( CAN_CURRENT_ID     | (cfg.board_ID << 4) ,
                                                  &current[0], &current[1]);

        /**********************************************************************/
        // convert 16bit ADC result into 2x 8bit for CAN message
        // one CAN message can transport up to 8 bytes

        /**********************************************************************/
        // CHANNEL 0
        CAN_send_uint16s(CAN_ADC_MSG_ID_CH0 | (cfg.board_ID << 4), 4,
            avr_adcBuf_GAIN_0[0], avr_adcBuf_GAIN_0[1],
            avr_adcBuf_GAIN_1[0], avr_adcBuf_GAIN_1[1]
            );

        /**********************************************************************/
        // CHANNEL 1
        CAN_send_uint16s(CAN_ADC_MSG_ID_CH1 | (cfg.board_ID << 4), 4,
            avr_adcBuf_GAIN_0[2], avr_adcBuf_GAIN_0[3],
            avr_adcBuf_GAIN_1[2], avr_adcBuf_GAIN_1[3]
            );
        /**********************************************************************/
        // send internal data
        CAN_send_uint16s(CAN_UC_STATUS | (cfg.board_ID << 4), 2,
            avr_adcBuf_GAIN_0[4], avr_adcBuf_GAIN_0[5]
            );
    }

    /***************************************************************************
     * Send out periodic CAN messages for I2C bus
     **************************************************************************/
#if defined(I2C_SENSOR_READOUT)
    // I2C sensors
    if( cnt_can_i2c_tmp100 >= cfg.interval_I2C_TMP100
        && cfg.interval_I2C_TMP100 < 255){
      cnt_can_i2c_tmp100 = 0;
      uint16_t tmp100 = i2c_read_TMP100(&hi2c1, 0x48);
      CAN_send_uint16s(CAN_I2C_MSG_TMP100 | (cfg.board_ID << 4), 1, tmp100 );
    }
    if( cnt_can_i2c_bme680 >= cfg.interval_I2C_BME680
        && cfg.interval_I2C_BME680 < 255){
      //TODO to be implemented
    }
#endif
  } // while(1)
  /* USER CODE END 3 */
} // void main()

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


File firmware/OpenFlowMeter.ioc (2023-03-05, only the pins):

Mcu.UserName=STM32F103C8Tx
PA0-WKUP.Signal=ADCx_IN0
PA1.Signal=ADCx_IN1
PA10.Signal=USART1_RX
PA13.Signal=SYS_JTMS-SWDIO
PA14.Signal=SYS_JTCK-SWCLK
PA15.Signal=S_TIM2_CH1_ETR
PA2.Signal=ADCx_IN2
PA3.Signal=ADCx_IN3
PA4.GPIO_Label=SEL_GAIN_I
PA4.Signal=GPIO_Output
PA5.GPIO_Label=SEL_GAIN_U
PA5.Signal=GPIO_Output
PA6.Signal=S_TIM3_CH1
PA7.Signal=S_TIM3_CH2
PA9.Signal=USART1_TX
PB0.GPIO_Label=LED3
PB0.Signal=GPIO_Output
PB1.GPIO_Label=LED4
PB1.Signal=GPIO_Output
PB10.Signal=I2C2_SCL
PB11.Signal=I2C2_SDA
PB12.Signal=SPI2_NSS
PB13.Signal=SPI2_SCK
PB14.Signal=SPI2_MISO
PB15.Signal=SPI2_MOSI
PB3.Signal=S_TIM2_CH2
PB4.GPIO_Label=LED2
PB4.Signal=GPIO_Output
PB5.GPIO_Label=LED1
PB5.Signal=GPIO_Output
PB6.Signal=I2C1_SCL
PB7.Signal=I2C1_SDA
PB8.Signal=CAN_RX
PB9.Signal=CAN_TX
PD0-OSC_IN.Signal=RCC_OSC_IN
PD1-OSC_OUT.Signal=RCC_OSC_OUT

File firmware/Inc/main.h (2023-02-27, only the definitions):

#define SEL_GAIN_I_Pin GPIO_PIN_4
#define SEL_GAIN_I_GPIO_Port GPIOA
#define SEL_GAIN_U_Pin GPIO_PIN_5
#define SEL_GAIN_U_GPIO_Port GPIOA
#define LED3_Pin GPIO_PIN_0
#define LED3_GPIO_Port GPIOB
#define LED4_Pin GPIO_PIN_1
#define LED4_GPIO_Port GPIOB
#define LED2_Pin GPIO_PIN_4
#define LED2_GPIO_Port GPIOB
#define LED1_Pin GPIO_PIN_5
#define LED1_GPIO_Port GPIOB
#define STDOUT_UART huart1

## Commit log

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2021-12-08 Layout CH2 & 100n deboucing Cs
    Copied layout from Channel 1 to Channel 2 and added 100n Cs to +24V rails
    [OpenFlowMeter.kicad_pcb, OpenFlowMeter_CurrentSource.sch]
2021-12-08 Removed SPICE directives
    because they create errors, when syncing PCB and schematic, because obviously, they cannot have a footprint.
    [OpenFlowMeter_CurrentSource.sch]
2021-12-08 Added passive filtering
    passive filtering to smoothen the analog voltage instead of real DAC.
    Using PWM and the ADC inside the microcontroller reduces the number of components.
    [OpenFlowMeter.kicad_pcb, OpenFlowMeter.sch, OpenFlowMeter_CurrentSource.sch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]
2021-12-08 Removed sub schematics
    They are now included in other parts, and the components are no longer needed.
    [OpenFlowMeter_ADC.sch, OpenFlowMeter_DAC.sch]
2022-01-07 Changed to KiCAD v6
    opened and converted project to KiCAD version 6
    [OpenFlowMeter.kicad_pcb, OpenFlowMeter.kicad_sch, OpenFlowMeter_Controller.kicad_sch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]
2022-01-07 fixed #auto_saved_files#
    # is comment in ignore, so redefined this rule
    [OpenFlowMeter_CurrentSource.kicad_sch]
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2022-01-07 intermediate commit
    updated schematics and started with controller section
    layout proceeded with PWM filter
    [OpenFlowMeter.kicad_pcb, OpenFlowMeter.kicad_sch, OpenFlowMeter_Controller.kicad_sch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]
2022-01-08 Updated controller pin assignment
    started thinking again about controller pin assingment.
    IOC and SCH matches
    [OpenFlowMeter_Controller.kicad_sch]
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2022-01-09 added CAN Transceiver
    added SN65HVD231 3.3V CAN Transceiver in order to connect multiple flow meter to a single bus.
    [OpenFlowMeter.kicad_pcb, OpenFlowMeter_Controller.kicad_sch]
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2022-01-09 Added crystal for STM32
    added 12 MHz MT crystal for STM32's clock input
    [OpenFlowMeter.kicad_pcb, OpenFlowMeter.kicad_sch, OpenFlowMeter_Controller.kicad_sch]
2022-01-11 added LEDs and further routing
    Added 4 LEDs, which can display the status
    partially done routing of LEDs
    [OpenFlowMeter.kicad_pcb, OpenFlowMeter.kicad_sch, OpenFlowMeter_Controller.kicad_sch]
2022-01-11 BUGFIX footprint of LT1490
    Footprint of LT1490 is SOIC8 and not Micro 8 -> had to enlarge the board.
    At the same step, changed all footprints from handsolder to normal solder. (saves a little space)
    [OpenFlowMeter.kicad_pcb, OpenFlowMeter.kicad_sch, OpenFlowMeter_Controller.kicad_sch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]
2022-01-11 Updated IOC file
    fixed clock source and frequency. Added all LEDs.
    [OpenFlowMeter.ioc]
2022-01-12 fixed layout
    Fixed layout to host lager amplifier footprints.
    Still some DRC warnings, but mostly regarding Silkscreen / Soldermask issues.
    [OpenFlowMeter.kicad_pcb, OpenFlowMeter_Controller.kicad_sch]
2022-01-12 board DRC clean
    removed all DRC warnings / errors
    had to waive some because Silkscreen is colliding with Board Edges and components are placed too close to footprints. (SMD pin header)
    [OpenFlowMeter.kicad_pcb]
2022-01-12 added ADC protection
    added Zener diodes as ADC input protection in combination with current limiting resistors.
    [OpenFlowMeter.kicad_pcb, OpenFlowMeter.kicad_sch, OpenFlowMeter_Controller.kicad_sch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]
2022-01-12 added write protection to EEPROM
    added jumper, which can be opened and then the EEPROM is write protected.
    [OpenFlowMeter.kicad_pcb, OpenFlowMeter.kicad_sch, OpenFlowMeter_Controller.kicad_sch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]
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2022-01-20 small update
    some very small changes from my approach of simulating eveything using KiCAD
    [OpenFlowMeter.kicad_pcb, OpenFlowMeter_CurrentSource.kicad_sch]
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2022-01-20 fixed CAN bitrate
    fixed CAN bitrate to 500kbit/s
    [OpenFlowMeter.ioc, can.c, main.c]
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2022-01-21 included values from simulation
    added values to those components, which did not had one
    [OpenFlowMeter.kicad_pcb, OpenFlowMeter.kicad_sch, OpenFlowMeter_Controller.kicad_sch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]
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2022-01-26 Include short description on SmartTest Error
    Error is caused by JP2, which is a solder jumper closed by default.
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2022-01-26 added I2C pullups
    previous version I have forgotten to add the I2C pullup resistors. Implemented them and added them to the layout.
    [OpenFlowMeter.kicad_pcb, OpenFlowMeter.kicad_sch, OpenFlowMeter_Controller.kicad_sch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]
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2022-02-03 added blinking of all LEDs
    due to the connection of the LED, here SET is OFF and RESET is ON
    [main.c]
2022-02-03 added comment of placed resistor value
    Because I had a temporary shortage on 10k resistors, I used 8k2 here.
    [OpenFlowMeter_Controller.kicad_sch]
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2022-02-04 change CAN_send_data_frame to use data
    use data instead of a fixed payload.
    changed main loop to increase the data by one
    [can.c, main.c]
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2022-02-06 fixed period of TIM4 OC
    [tim.c]
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2022-02-06 fixed formatting of debug output
    [can.c]
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2022-02-20 added measurement script for testing the stability
    sets a certain DAC value and reads back the voltage and current measured.
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2022-03-07 replaced manual reading of current with multimeter
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2022-03-08 added zener diode reverse voltage and current
    added both measured data as well as plotting script
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2022-03-12 implemented changes from tests with the prototype
    schematic is updated, layout needs to be done.
    [OpenFlowMeter.kicad_pcb, OpenFlowMeter.kicad_sch, OpenFlowMeter_Controller.kicad_sch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]
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2022-03-14 tuned PID settings, fixed plotting
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2022-05-31 proceeded routing for rev 2
    placed all components roughly, some checks needed, it is getting crowded in some areas...
    [OpenFlowMeter.kicad_pcb]
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2022-09-27 inlcuded switching gain amplifier
    aim is to increase the voltage and current reading for small currents and voltages.
    [OpenFlowMeter.kicad_sch, OpenFlowMeter_Controller.kicad_sch, OpenFlowMeter_CurrentSource.kicad_sch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]
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2022-09-27 almost fixed Git Mess Up
    [OpenFlowMeter.kicad_pcb]
2022-09-28 starting finishing the layout
    some distances are not 100% and some components are too close together
    [OpenFlowMeter.kicad_pcb, OpenFlowMeter_PWM_Filter.kicad_sch]
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2022-09-28 fixed Layerstack
    matched layerstack to AISLER 4 layers HD
    https://aisler.community/t/4-layer-hd-pcb-stackup/86
    [OpenFlowMeter.kicad_pcb]
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2022-09-29 Silkscreen cleanup
    removed KiCAD Logo (it's to large to fit on the PCB)
    [OpenFlowMeter.kicad_pcb]
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2022-10-20 fixed DRC for TMP100
    [OpenFlowMeter.kicad_pcb, OpenFlowMeter.kicad_sch, OpenFlowMeter_Controller.kicad_sch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]
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2022-10-26 added resistors at the amplifier output
    these can decouple the filter / averaging capacitors from the op amp output and hence prevent ringing, oscillation.
    [OpenFlowMeter.kicad_sch, SwitchGainAmp.kicad_sch]
2022-10-26 added BME680 I2C sensor
    Measurement of pressure / temperature and humidity and VOC. This might influence the flow and for ambient flow, this might be an option to measure and correct for them.
    For measurements inside pipes, the gas through pipes are normally known and hence the correction should be known as well.
    [OpenFlowMeter.kicad_pcb, OpenFlowMeter.kicad_sch, OpenFlowMeter_I2Ccomponents.kicad_sch]
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2022-11-12 fixed revision in PCB document
    [OpenFlowMeter.kicad_pcb]
2022-12-10 fixed missing curly bracket
    [i2c_scanner.c]
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2022-12-10 fixed printf output
2022-12-11 added some notes regarding production changes
    Some changes, because I did not had the right parts in my hands, some because I wanted to try different ones.
    [OpenFlowMeter.kicad_sch, OpenFlowMeter_Controller.kicad_sch, OpenFlowMeter_I2Ccomponents.kicad_sch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]
2022-12-14 fixed address alignment
    STM32 uses left aligned addresses
    [i2c_utils.c]
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2022-12-15 fixed unused variable
    by just printing if there has been an error
    [adc.c]
2022-12-16 adapted datatype of timer2_elapsed_old
    in order to prevent dead locks from overflow, its important, that this datatype and the one, which it is compared with matches.
    [main.c]
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2022-12-17 increased GND connections to controller
    removed one doubled 3V3 trace, which was slightly off, that it wasn't found by the KiCAD tools
    [OpenFlowMeter.kicad_pcb]
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2022-12-18 BUGFIX in bytelength, which is written
    [i2c_utils.c]
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2022-12-18 fixed comment to match, what is really done here
    [main.c]
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2022-12-20 fixed can message ID
    [main.c]
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2022-12-21 fixed PWM output alignment
    If channel 1 is changed it should also affect the data of voltage and current of channel 1 and the same for channel 0
    [can.c, main.c]
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2022-12-21 include T in PID configuration
    and fixed copy paste error
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2022-12-22 BUGFIX: use the high gain to determine the saturation
    and not the lower gain.
    [main.c]
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2022-12-31 converted project into KiCAD 6.99
    using 6.99.0-5192-g5e0064c21e release build, just to test the "new features"
    adapted page numbering (current source 1 was page 4 and CS 2 page 3)
    [OpenFlowMeter.kicad_pcb, OpenFlowMeter.kicad_sch, OpenFlowMeter_Controller.kicad_sch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]
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2023-01-02 fixed conversion from voltage into LSBs.
    added rounding first.
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2023-01-02 fixed the number of points for the stimulus current
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2023-01-04 added some sanitary printouts and fixed some naming issues
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2023-01-05 added plot of the corrected resistance
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2023-01-06 BUGFIX: current bias is stored in mA, but calculations are in A
    [main.c]
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2023-01-08 added Hysteresis for saturation, to prevent flickering
    at the same time, this gives a more stable temperature calculation
    [main.c]
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2023-01-09 removed no longer needed variable (resistance) and imports
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2023-01-09 BUGFIX: save currents in current array
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2023-02-27 changed U8 to LT1491
    get some space on the PCB by removing the non needed pads
    [OpenFlowMeter.kicad_pcb, SwitchGainAmp.kicad_sch]
2023-03-01 updated SWD connector to 1x4 pins
    the other two pins are not really needed at all.
    [OpenFlowMeter.kicad_pcb, OpenFlowMeter_Controller.kicad_sch]
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2023-03-01 updated debug interface to SWD only
    prepared for second 2 PWM outputs
    [OpenFlowMeter_Controller.kicad_sch]
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2023-03-02 fixed input / output numbering
    [OpenFlowMeter_PWM_Filter.kicad_sch]
2023-03-02 changed gain switch to CD4066
    this analog switch allows usage of a bias voltage
    [SwitchGainAmp.kicad_sch]
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2023-03-02 renamed PWM connections
    to get the link to the Timer and the Channel
    [OpenFlowMeter_Controller.kicad_sch]
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2023-03-03 updated connector to 1x4
    this allows 4 wire connection of the PT100.
    [OpenFlowMeter_CurrentSource.kicad_sch]
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

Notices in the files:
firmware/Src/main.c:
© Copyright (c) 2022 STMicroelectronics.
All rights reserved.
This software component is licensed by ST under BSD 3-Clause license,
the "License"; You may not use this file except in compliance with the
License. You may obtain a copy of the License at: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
